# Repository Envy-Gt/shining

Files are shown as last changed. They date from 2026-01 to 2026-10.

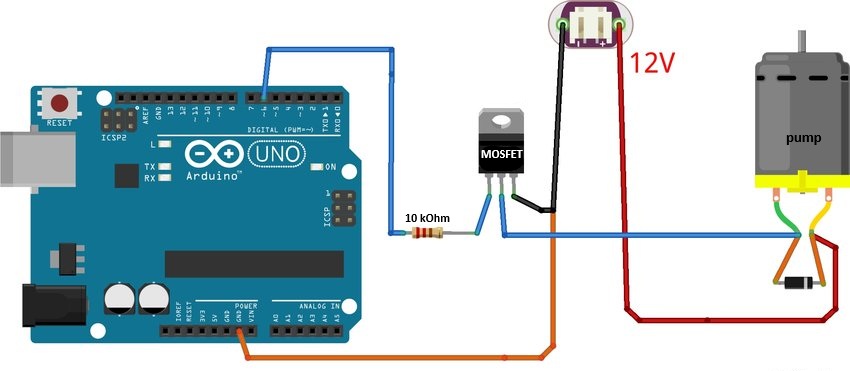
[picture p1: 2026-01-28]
images/wiring/wiring_alim.jpg

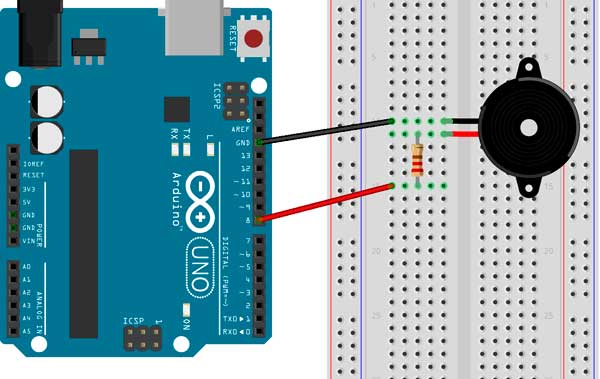
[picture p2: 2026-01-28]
images/wiring/buzzer_wiring.jpg

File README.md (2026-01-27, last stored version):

# shining
Description : Shining is an all in one DIY electroplating machine that answers those constraints : It can be used without an external generator with consistent results even with minimum knowledge of the practice, as safe as possible to use and Fully made with only generic parts and a standard 3D printer

 # What’s electroplating ? 

 Electroplating or electroforming consists of using electricity to depose a thin layer of metal (copper, nickel, palladium, gold…) on a conductive piece.
Electroplating can be used in many diy fields like jewelry, electronics or miniatures painting

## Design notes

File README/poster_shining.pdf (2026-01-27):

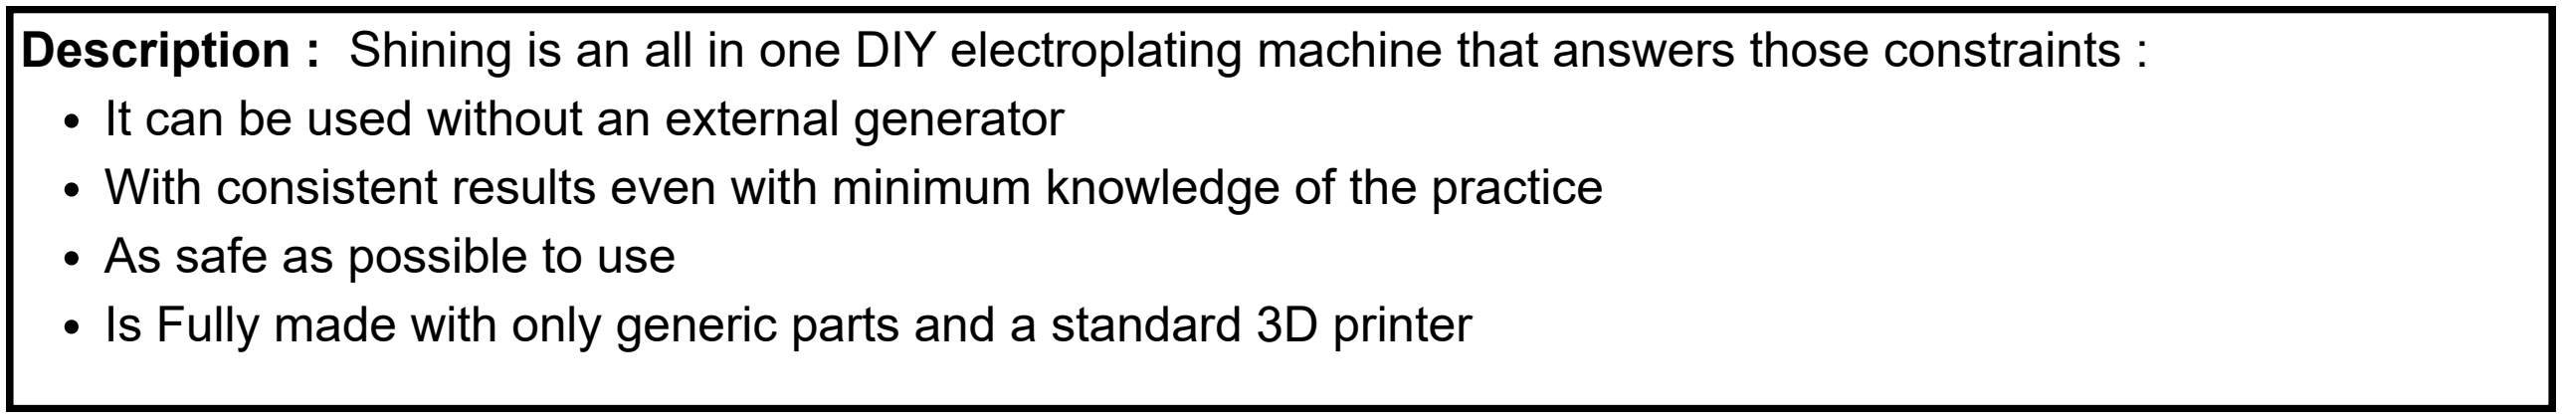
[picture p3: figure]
As safe as possible to use

Description : Shining is an all in one DIY electroplating machine that answers those constraints :

## It can be used without an external generator With consistent results even with minimum knowledge of the practice

## Is Fully made with only generic parts and a standard 3D printer

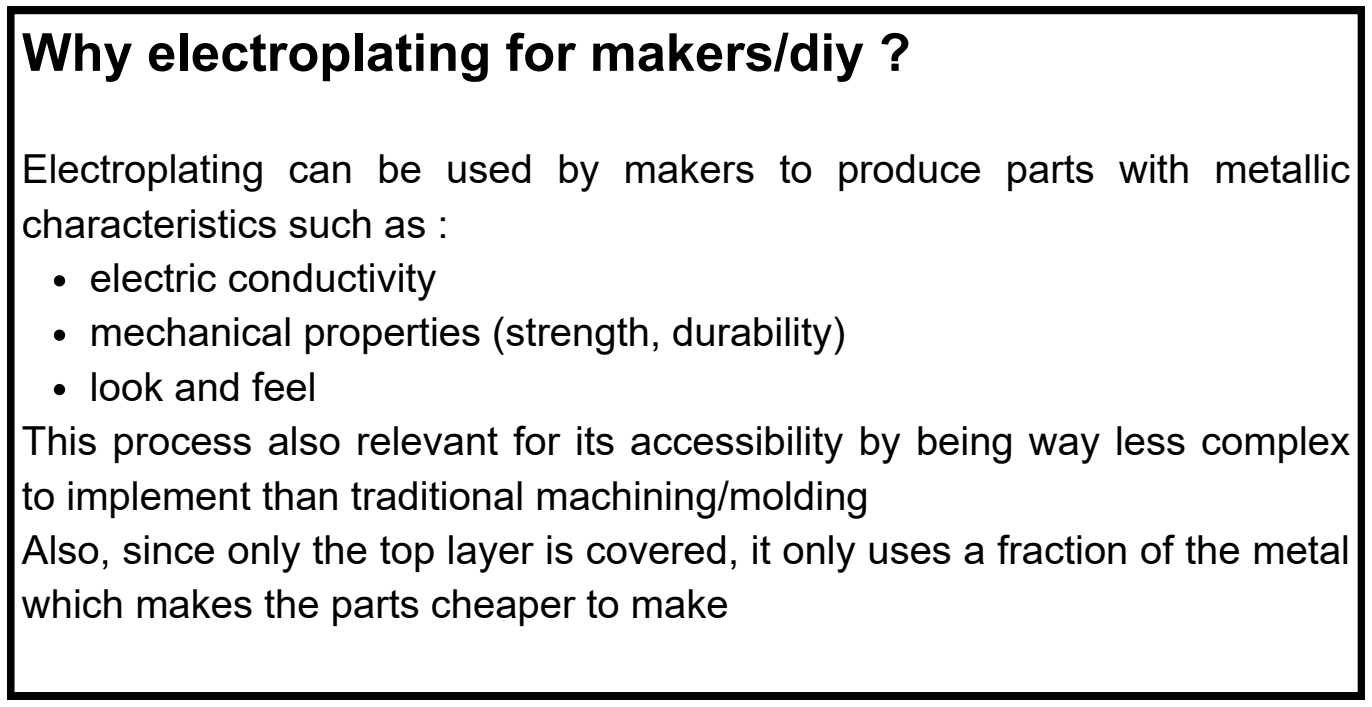
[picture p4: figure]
Why electroplating for makers/diy ?; characteristics such as : electric conductivity mechanical properties (strength, durability) look and feel; to implement than traditional machining/molding; which makes the parts cheaper to make
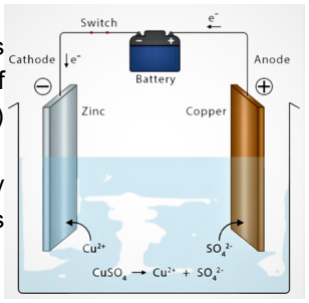
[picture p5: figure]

Electroplating can be used by makers to produce parts with metallic

This process also relevant for its accessibility by being way less complex

Also, since only the top layer is covered, it only uses a fraction of the metal

## What am I proposing ?

This system (shining) aims at being as simple, cheap, and robust as possible.

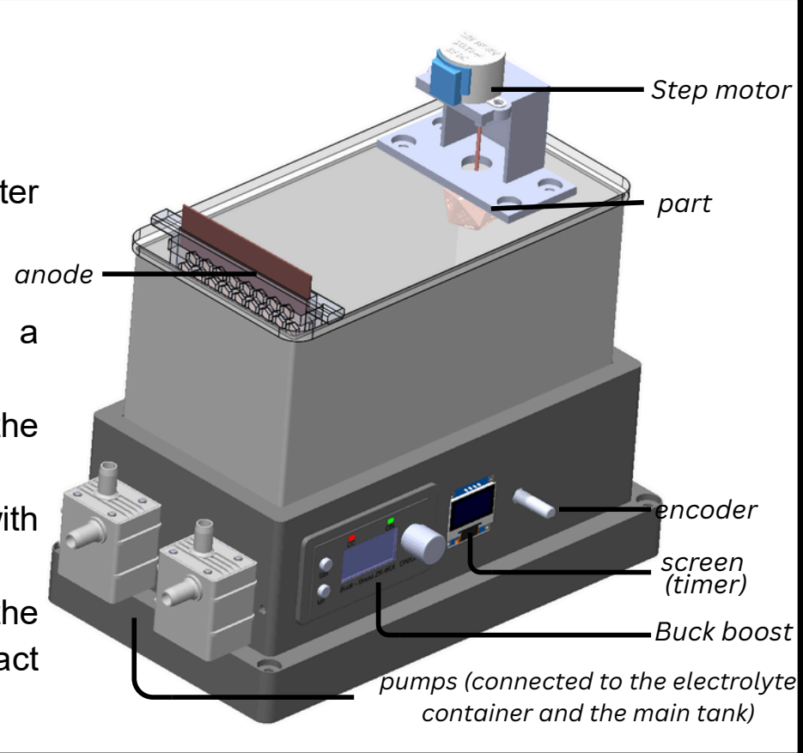
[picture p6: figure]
anode; encoder; screen (timer); Buck boost; part; Step motor; pumps (connected to the electrolyte container and the main tank)

It can be totally assembled for less than 150€ (electrolyte solution aside) with a standard 3D printer and a few generic part (arduino uno, 5V step motor, 12V pumps, encoder, oled screen...)

It works around a Buck Boost Zk-4KX (regularly used to make diy power supplies) which provide a constant current between the part and the anode (copper, nickel, zinc...)
To use it, the user attach the part (connected to the - of the supply) to the step motor and connect the anode (+ of the supply).
They then enter the plating duration with a simple encoder which activated a pump to fill the tank with the acidic electrolyte (closing the circuit and beginning the plating).
The part is rotated in order to assure uniform plating. When the timer ends (the plating stops), the electrolyte solution is sucked out by a second pump and replaced in its container (reducing contact with the user)

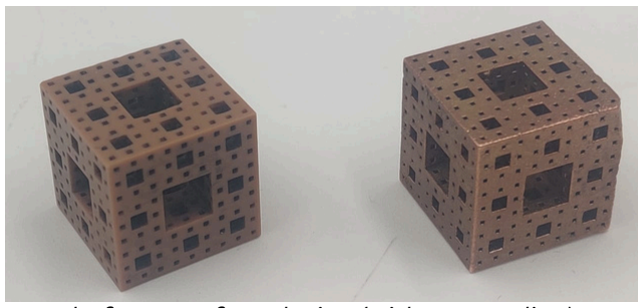
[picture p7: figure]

## My results (so far) :

What works :
+ the parts are evenly plated with a thick coating (+30% in weight)
+ strong bond between the part and the metal (no detachment observed)
+ the plating makes the parts utterly conductive in a way that isn’t attainable with conductive paint

Whats left to improve
- the parts come out rough and need some sanding for a smooth finish
- attaching the part to the step motor and can be a little fiddly
- only works for small parts (> 9 cm in diameter)
- test needs to be done to evaluate the thickness of the coating in order to adjust tolerances for mechanical parts
- a fume extractor is needed to make the system safe in places with not enough ventilation
before plating | after plating and sanding

# SHINING : Conception and Implementation of a Do-It-Yourself

Electroplating Machine Project intended for individual use (makers).

# Augustin Berthomier, Antoine Pradoura, Marc Teyssier

## What’s electroplating ?

Electroplating or electroforming consists of using electricity to depose a thin layer of metal (copper, nickel, palladium, gold…) on a conductive piece.
Electroplating can be used in many diy fields like jewelry, electronics or miniatures painting

before an after plating (without sanding)

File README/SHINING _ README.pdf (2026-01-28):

# SHINING : README

### Components

- 1 Arduino Uno R3 (http://amazon.fr/Arduino-A000066-M%C3%A9moire-flash-32/dp/B008GRTSV6) or any board with the required pins (see the arduino code)
- 1 Buck Boost ZK-4KX (https://www.amazon.fr/Convertisseur-Buck-Boost-dalimentation-Alimentation/dp/B0D44JVLTM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)
- 1 12V 3A power supply (https://www.amazon.fr/LianShi-Alimentation-transformateur-Courts-Circuits-lautomatisation/dp/B073GLDKMH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)
- 1 SSD-1306 (https://www.amazon.fr/dAffichage-Communiquer-R%C3%A9solution-Appareil-Intelligent/dp/B08VJGKCFT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)
- 1 KY-040 encoder (https://www.amazon.fr/AZDelivery-Encodeur-Compatible-Raspberry-incluant/dp/B079H3C98M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)
- 2 12V DC brushless mini pump (https://www.amazon.fr/dp/B0CYC8ZXWH?aref=9a1uacqCT4&sp_csd=d2lkZ2V0TmFtZT1zcF9kZXRhaWwy) or any 12V DC mini pump that doesn’t require to be submerged (a peristaltic pump would be best)
- 1 3-24V buck module step down (https://www.amazon.fr/dp/B0FP51RK8T?aref=6MLL2bEfZb&sp_csd=d2lkZ2V0TmFtZT1zcF9kZXRhaWw)
- 1 28BYJ48 5V stepper + Driver ULN2003A (https://www.amazon.fr/reucteur-28BYJ48-stepper-ULN2003A-Arduino/dp/B071VGBJG3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)
- 2 MOSFET irfz44n (https://www.amazon.fr/Innfeeltech-Transistors-MOSFET-irfz44n-transistor/dp/B0D69Y4GKW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) (would also work with npn mosfets)
- 1 Buzzer 3-24 V (https://www.amazon.fr/sonnerie-%C3%A9lectrique-pi%C3%A9zo-%C3%A9lectrique-%C3%A9lectronique-pi%C3%A9zo%C3%A9lectrique/dp/B08J9TMZSV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)
- 1 galvanization tank (https://drgalva.fr/cuve-pour-galvanisation-grand-fr)
- 1 breadBoard
- Dupont jumper cables (male-male/female-male)
- clear acrylic sheet (3-5 mm)
- 4x6mm clear polyurethane (https://www.amazon.fr/HAXIHA-Pneumatique-Polyur%C3%A9thane-Compresseur-Pneumatiques/dp/B0DQ1HHC8T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) tube
- 3 10k Ohm resistors (https://www.amazon.fr/Sourcingmap-axial-plomb-r%C3%A9sistances-Carbone/dp/B0087ZDQQ0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)
- 4 M4x16mm screws
- 2 M4x8mm screws
- 4 M4 Washers
- 4 M2 screws (for mounting the screen)

### Consumables

- Bright blue copper electrolyte (https://drgalva.fr/cuivre-brillant-fr)
- pure copper anode (https://drgalva.fr/anode-en-cuivre-fr) (or any pure copper sheet)
- Copper threads (1-2mm for holding the part and 0.3-0.8) for best conductivity)
- conductive copper spray (https://www.tifoo.de/fr/spray-conducteur-en-cuivre)

### Equipment

- Standard 3D printer (PLA/TPU)
- Drill with 6mm and 12 mm bits (for the acrylic sheet)
- cutting tools for the acrylic sheet (dremel/handsaw/jigsaw…)
- hot glue gun

### Assembly

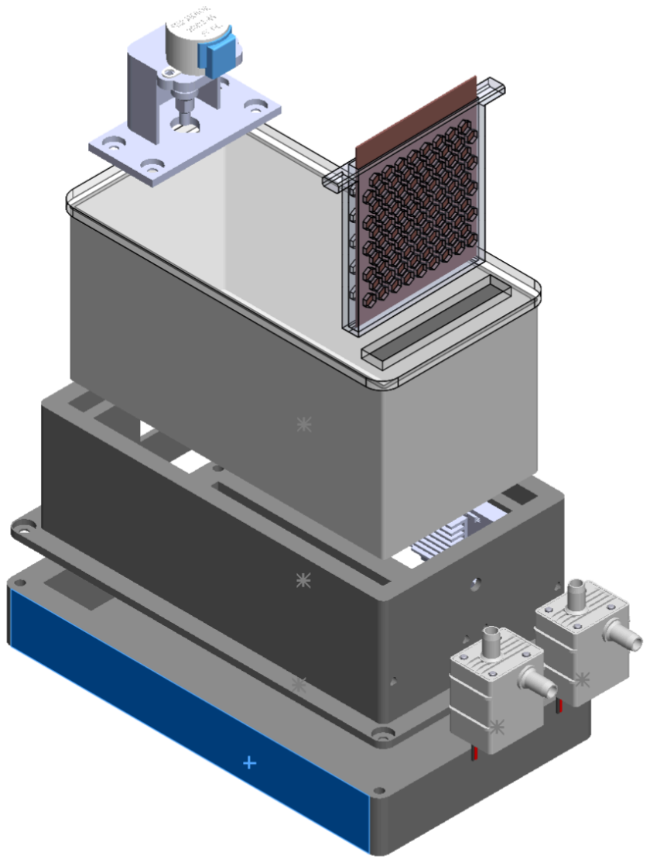
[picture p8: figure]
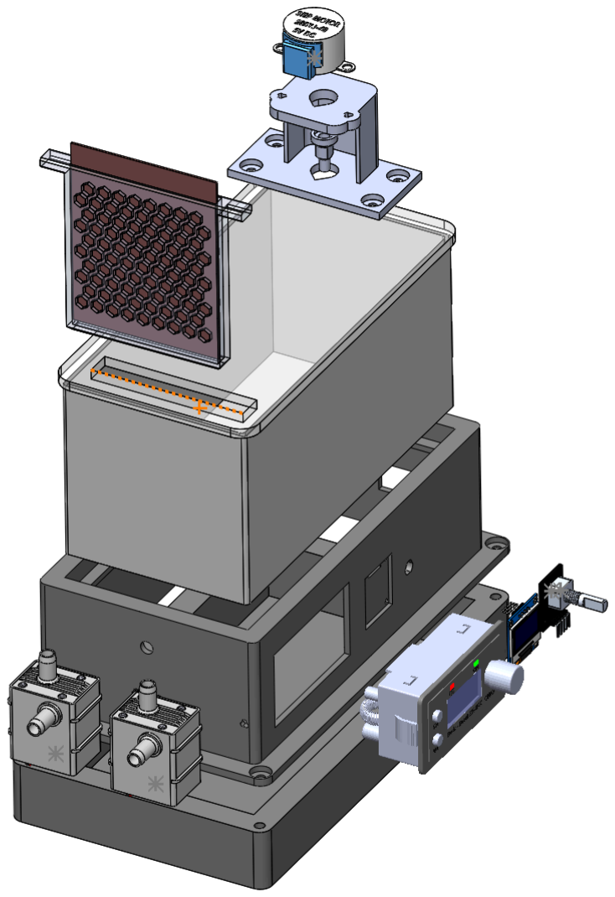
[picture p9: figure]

As seen in those pictures the assembly is pretty straight forward :
- the main frame (box_shining) is screwed on the base with washers and the tank simply sit on top of the mainframe
- the stepper compartment (step_holder) is held by 4 screws going through the acrylic sheet in another 3D printed part (-step_holder_2) (not seen in the 3D view)
- the acrylic sheet can’t be 3D printed, I added a DXF file that can be used as a guide when cutting or if possible, used for laser cutting the sheet
- the joint_TPU_Shining is glued on the acrylic and goes between it and the tank so that the lid does not move during use
- the tube is held in place at the bottom of the place by the embout_shining that is hot glued to the bottom wall (see image_embout)

For the electronic :

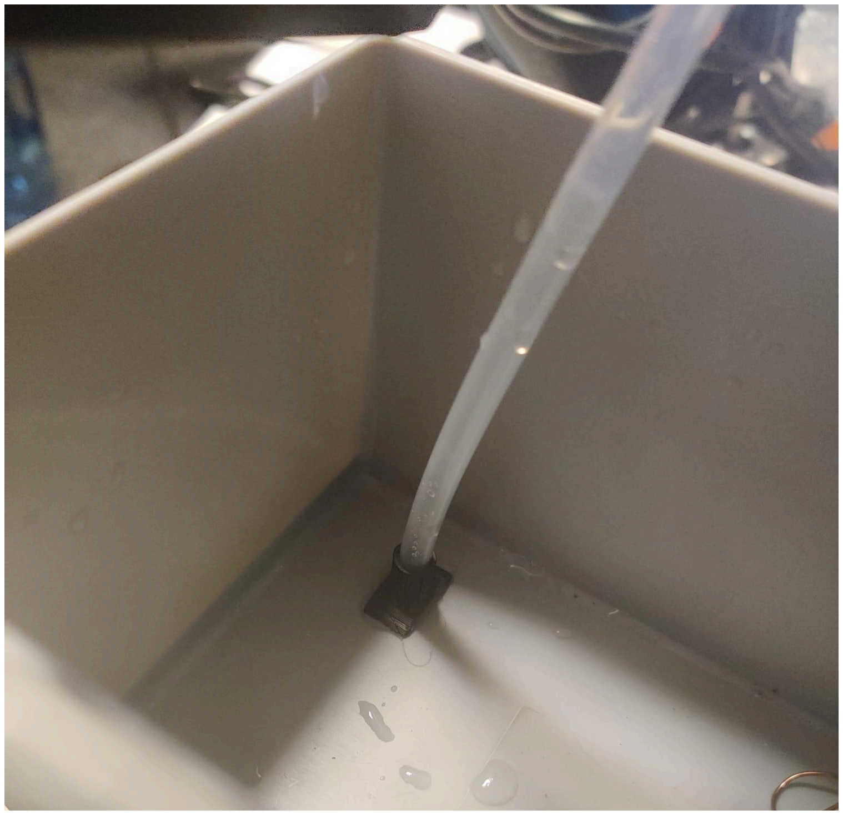
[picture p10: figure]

- the mini pumps are mounted with screws using an attachement, i’m using the one that came with mine but i will model a new one shortly
- the screen in mounted using m2 screws
- the encoder is already tapped and can be screwed directly on the frame
- the buck boost is a simple press fit
- Note that the power supply can’t be properly put in the frame if the buck boost is all the way in. To mount it, get it in by the under side of the frame, press it against the inner wall of the frame and push the buck boost in. it should lock it in place (see image_up).

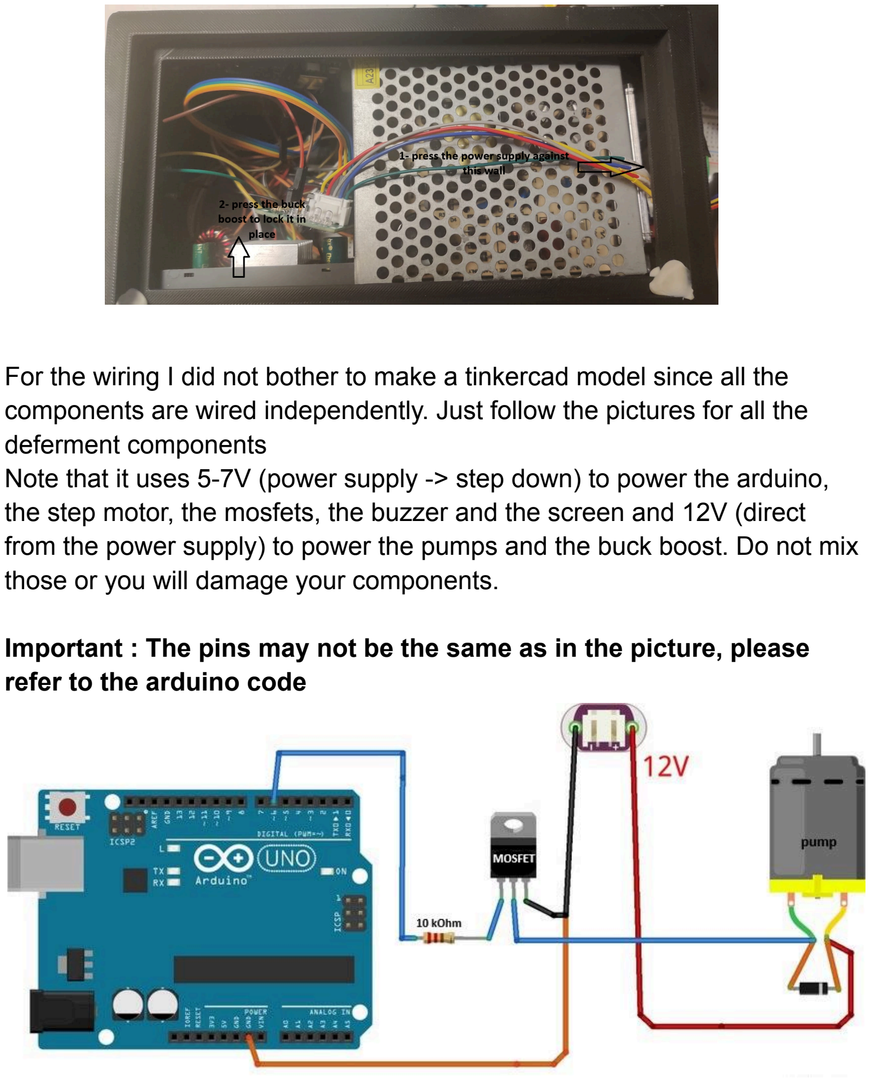
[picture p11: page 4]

For the wiring I did not bother to make a tinkercad model since all the components are wired independently. Just follow the pictures for all the deferment components
Note that it uses 5-7V (power supply -> step down) to power the arduino, the step motor, the mosfets, the buzzer and the screen and 12V (direct from the power supply) to power the pumps and the buck boost. Do not mix those or you will damage your components.

Important : The pins may not be the same as in the picture, please refer to the arduino code

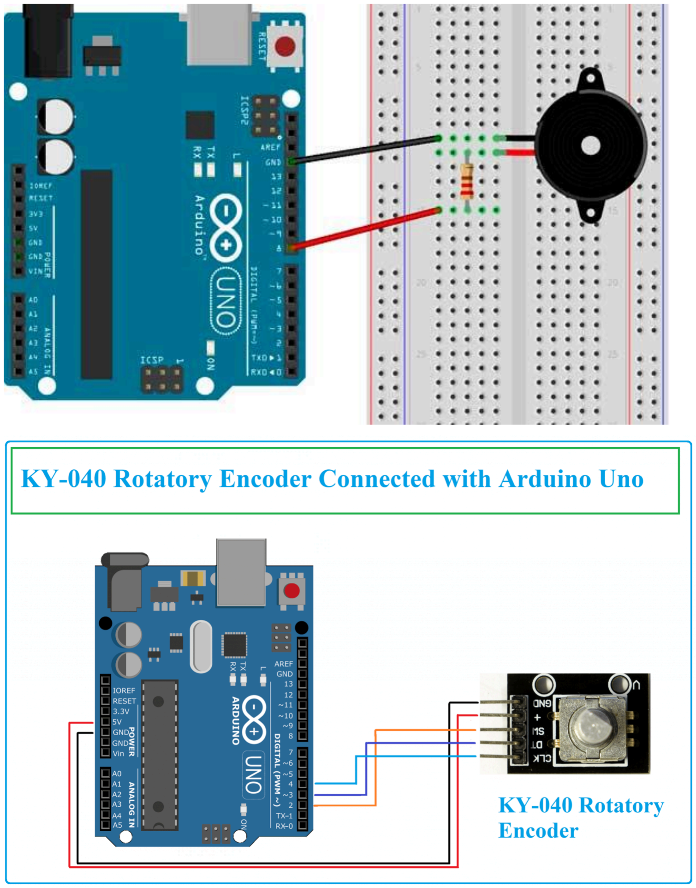
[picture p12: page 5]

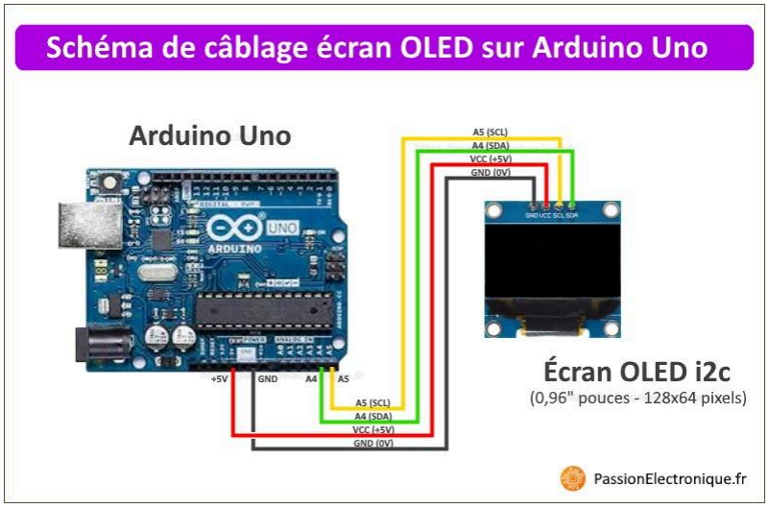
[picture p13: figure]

## How to use

Preparation :
- sand the target part correctly to avoid any imperfection to show through the plating
- spray the target part with a conductive spray (see components)
- once dried, wrap your part with thin copper wire to ensure conductivity
- take the thicker wire to make a hook and attach it to the stepper
- attach the part to the hook inside the tank so that it does not exceed ¾ of its height
- connect the part to the VOUT - and the anode to the VOUT + check the connection with a multimeter
- check that the tubing is well connected between the tank, the pump and the bottle of acid

Use

- 1 : power the device by plugging it (the is not on/off button)
- 2 : use the encoder to choose a timer and click to confirm
- the device will first pump the electrolyte in the tank
- Use the buck boost to choose the current, if everything is well connected and the value is correct (1A per Dm2) the constant current led should light up
- If you want to interrupt the possess, click on the encoder
- Upon interruption or at the end of the timer, the second pump will get the acid back in its bottle
- using gloves, take the piece and rinse it with water to neutralise the last drop of acid.
- you can now sand the piece for better results

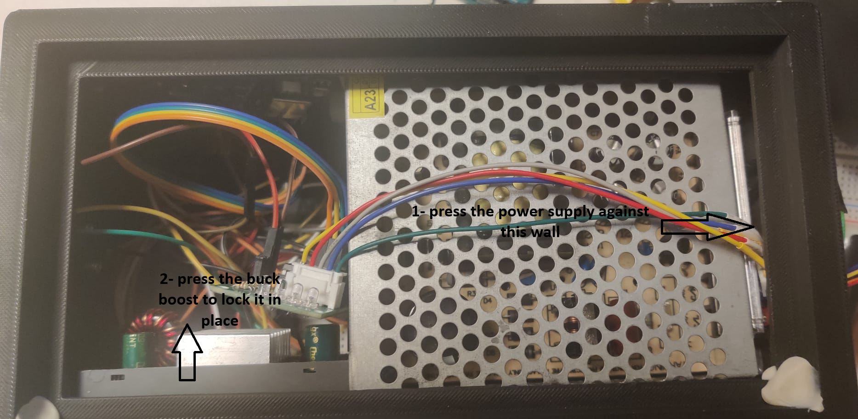
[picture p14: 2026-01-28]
images/pictures/image_up.png

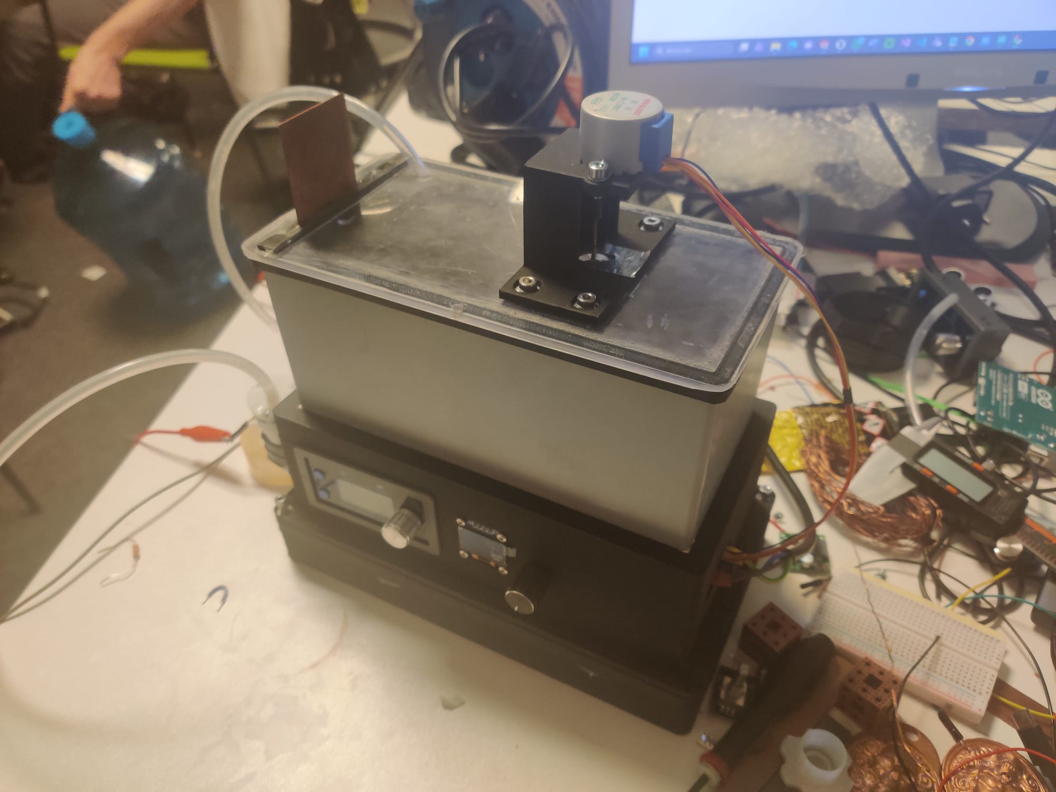
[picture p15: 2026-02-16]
images/pictures/image_whole.jpeg

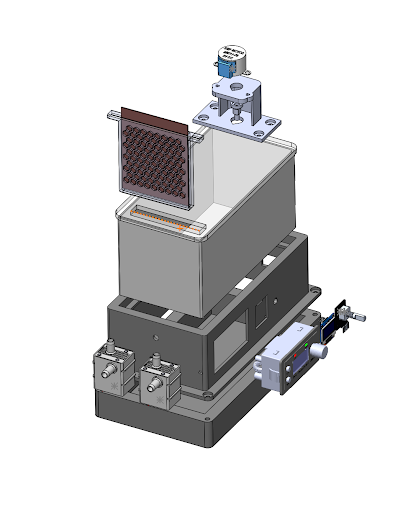
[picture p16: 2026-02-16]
images/3D_View_Shining/3D_View_2.png

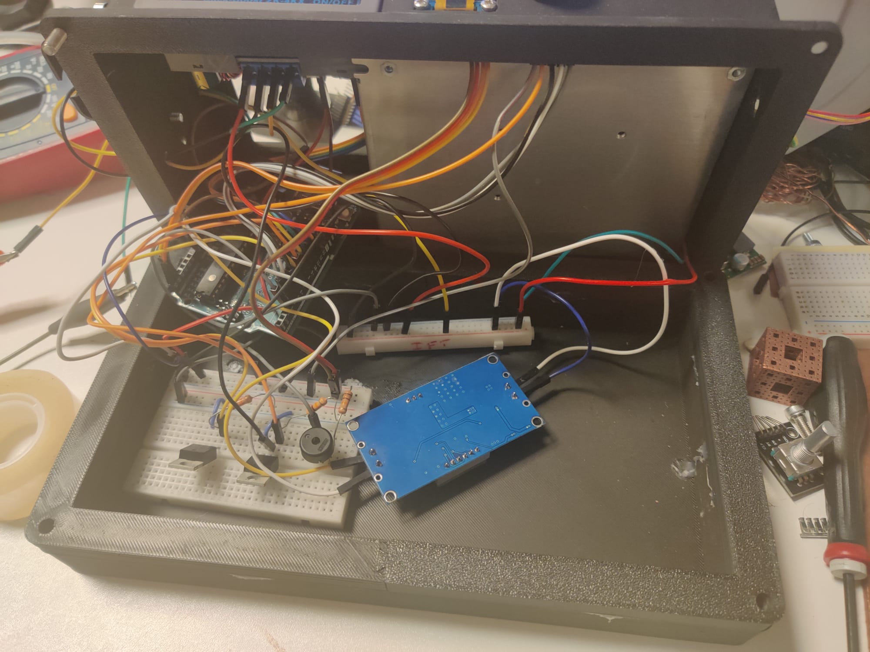
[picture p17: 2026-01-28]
images/pictures/image_inside.jpeg

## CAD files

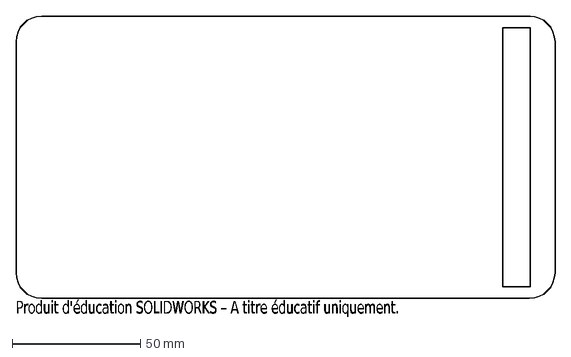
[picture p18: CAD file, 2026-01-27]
stencil for acrilic.DXF
Produit d'éducation SOLIDWORKS – A titre éducatif uniquement.

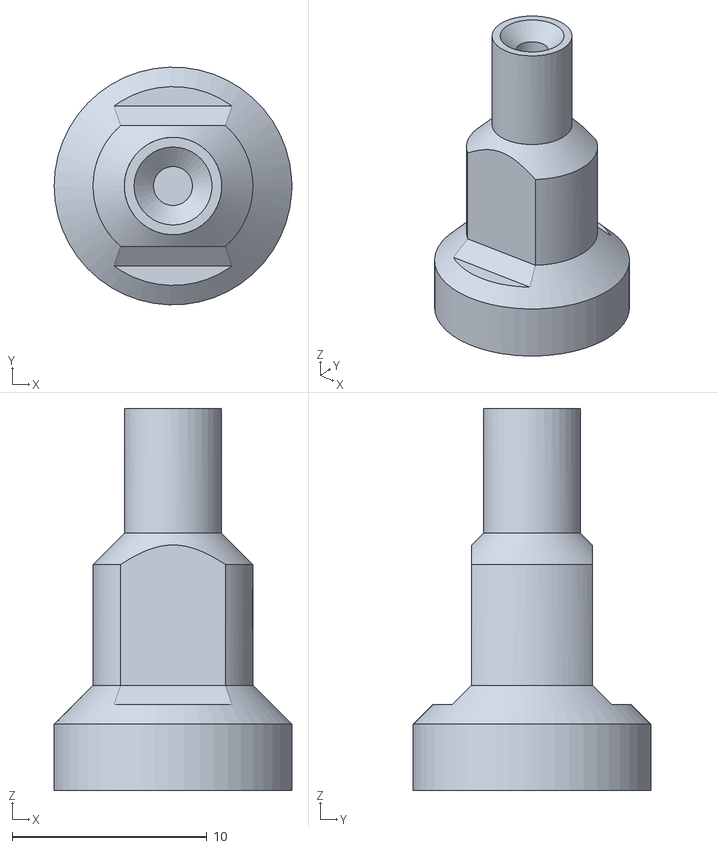
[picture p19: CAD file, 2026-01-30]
STL files/inter_shining.STL
12.2 x 12.2 x 19.6

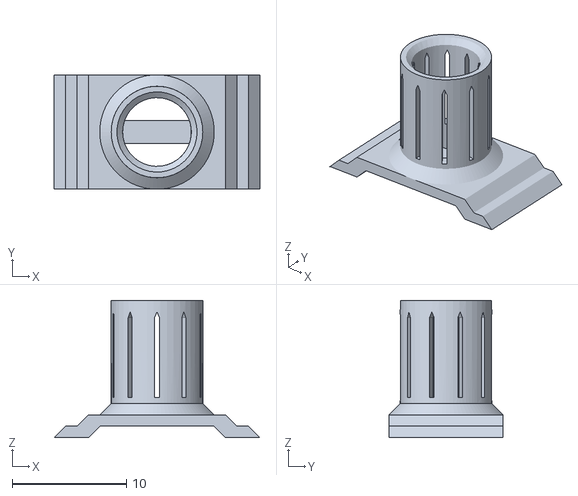
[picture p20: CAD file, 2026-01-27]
STL files/embout_shining.STL
18.0 x 10.0 x 12.0

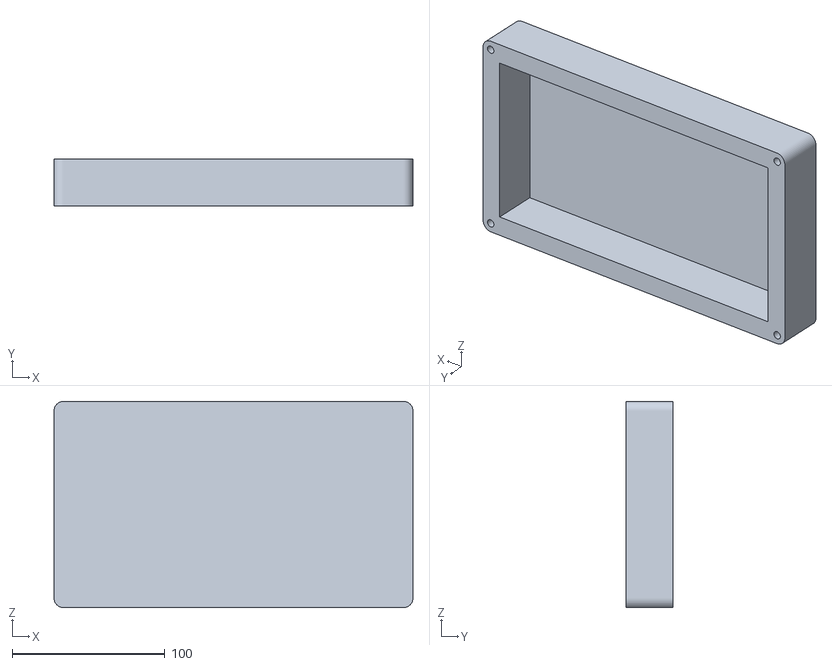
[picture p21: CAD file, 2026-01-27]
STL files/base_shining.STL
235.0 x 31.0 x 135.0

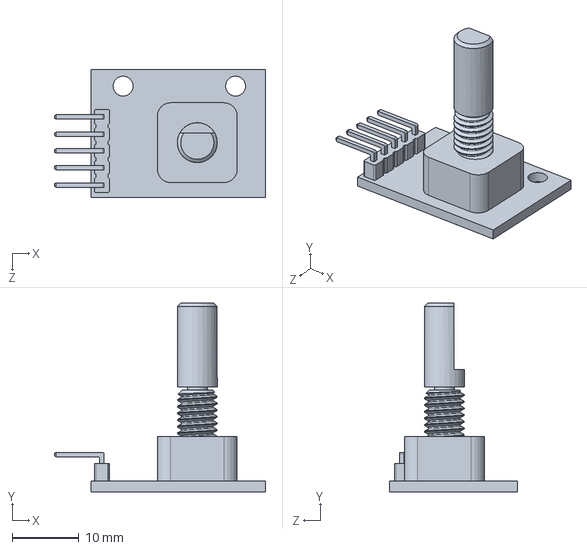
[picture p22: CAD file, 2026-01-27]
SLPRT files/User Library-S002 - Encoder KY040.SLDPRT
31.7 x 28.3 x 19.2 mm

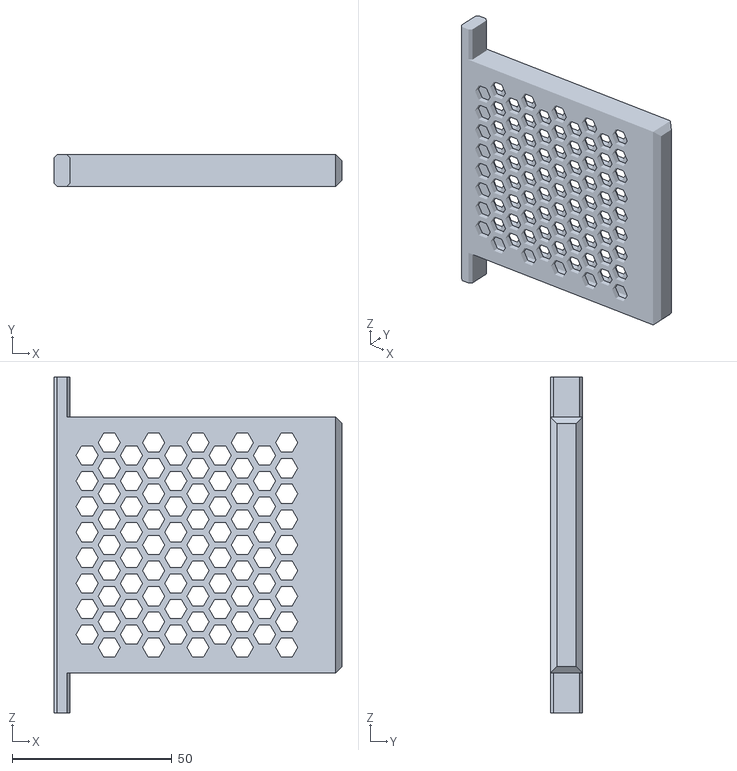
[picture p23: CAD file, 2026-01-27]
STL files/Panier_Shining.STL
90.0 x 10.0 x 105.0

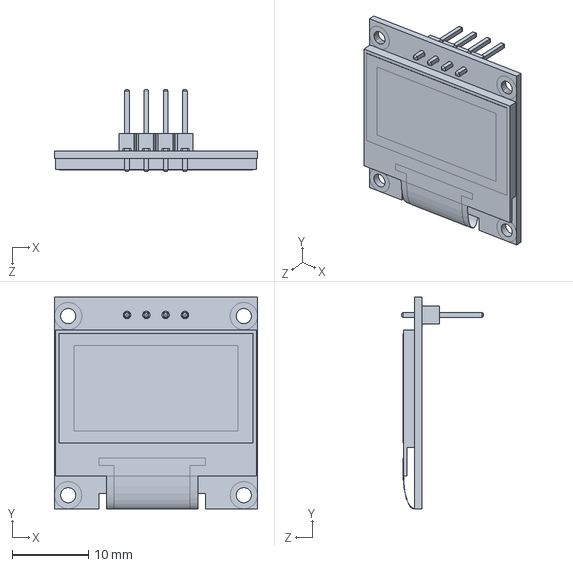
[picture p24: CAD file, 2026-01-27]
SLPRT files/User Library-128x64I2COLEDDisplayAdafruit.SLDPRT
26.7 x 27.9 x 10.8 mm

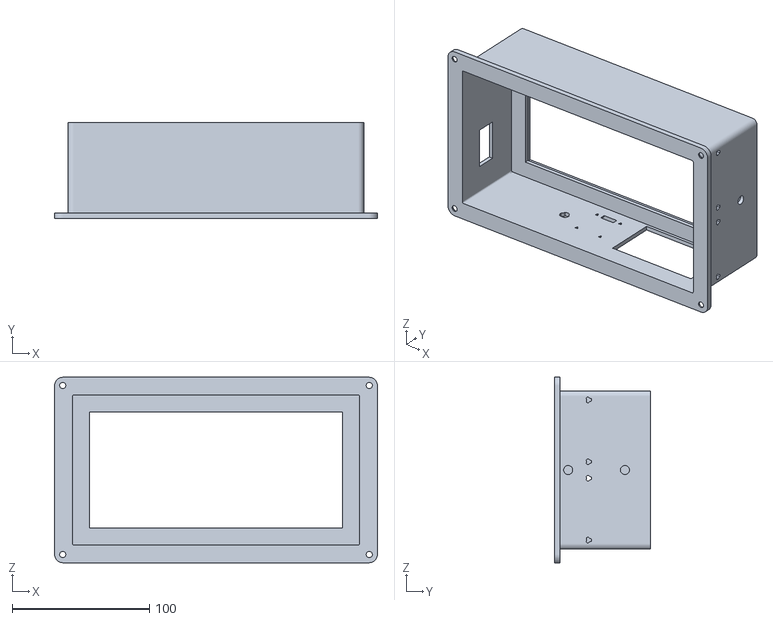
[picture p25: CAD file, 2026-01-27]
STL files/box_shining.STL
235.0 x 70.0 x 135.0

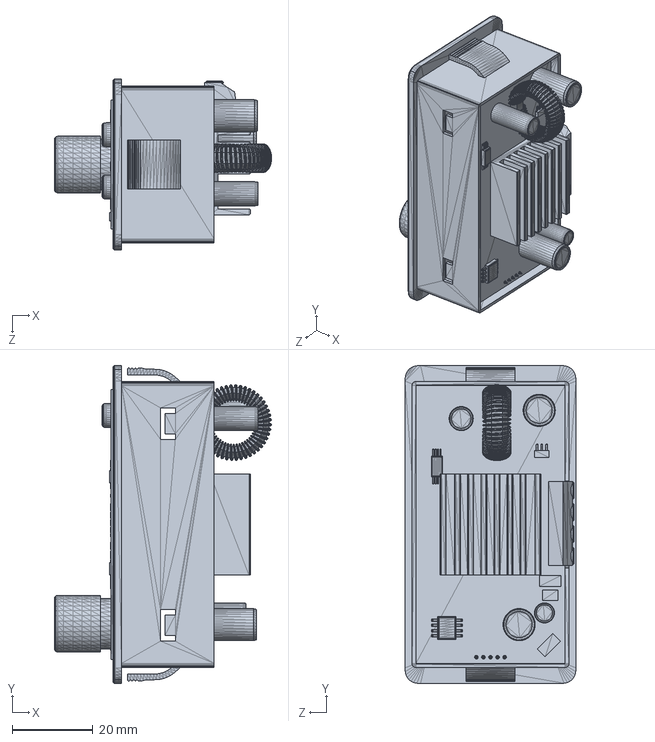
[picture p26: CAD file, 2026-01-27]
SLPRT files/ZK-4KX Buck Boost Converter.SLDPRT
53.9 x 79.0 x 42.5 mm

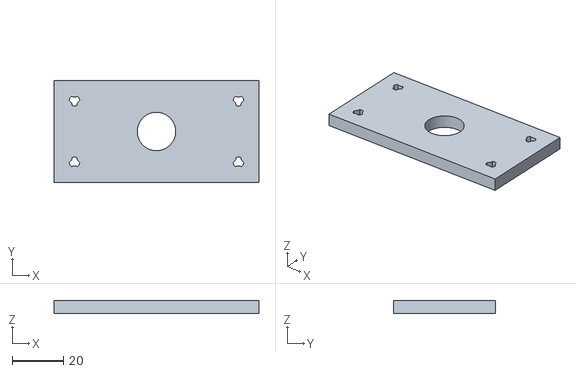
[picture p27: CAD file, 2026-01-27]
STL files/step_holder_2_shining.STL
80.0 x 40.0 x 5.00

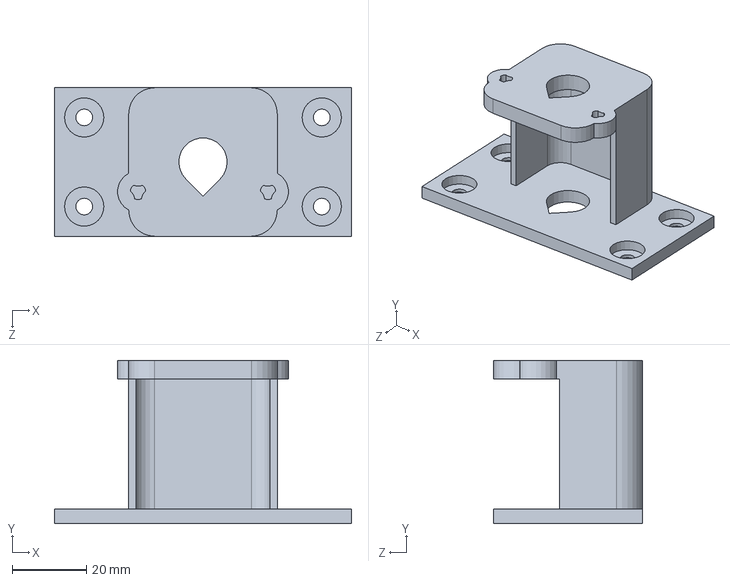
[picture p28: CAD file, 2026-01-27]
SLPRT files/step_holder_shining.SLDPRT
80.0 x 44.0 x 40.0 mm

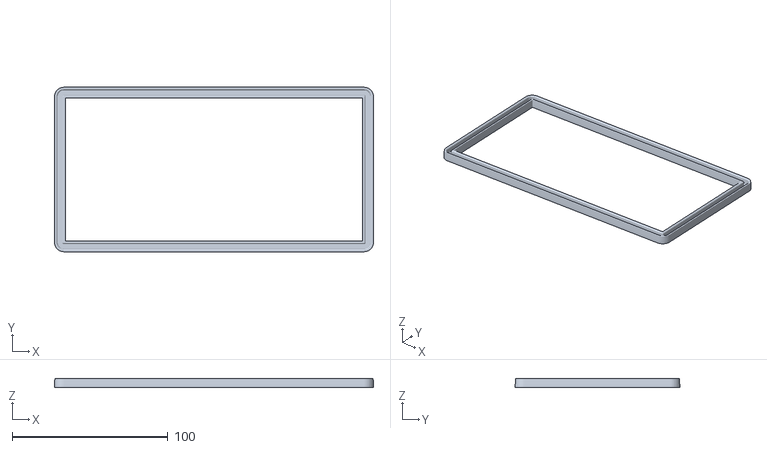
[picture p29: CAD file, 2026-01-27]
STL files/joint_TPU_Shining.STL
204.5 x 105.5 x 6.00

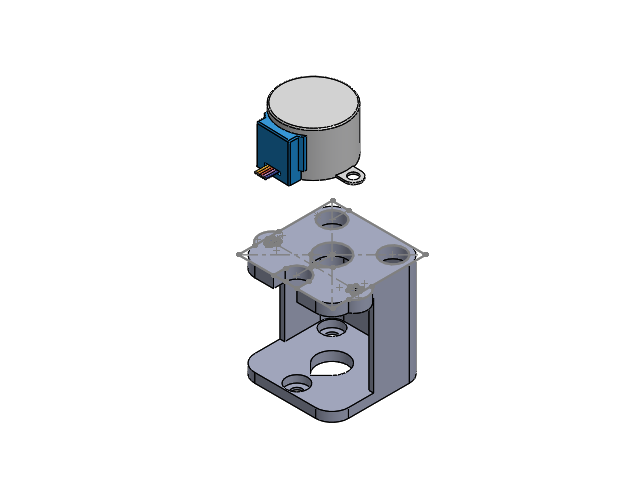
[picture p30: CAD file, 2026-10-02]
SLPRT files/Assemblage step.SLDASM
step holder
28BYJ-48.step

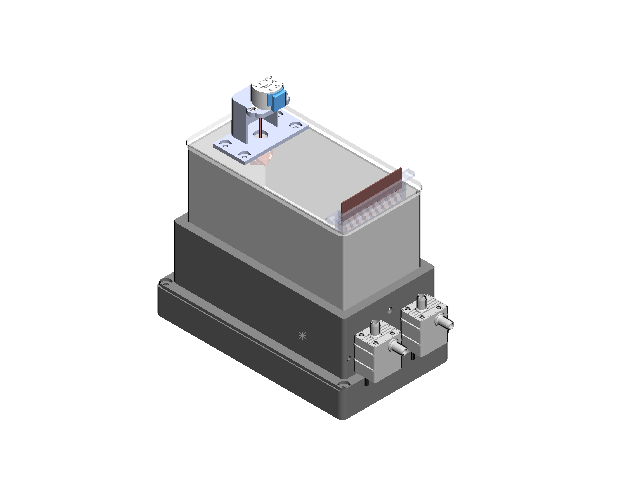
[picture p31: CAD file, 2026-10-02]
SLPRT files/Assemblage shining.SLDASM
box_shining
base_shining
step_holder_shining
Pièce2^Assemblage shining
Pièce3^Assemblage shining
User Library-128x64I2COLEDDisplayAdafruit
User Library-S002 - Encoder KY040
ZK-4KX Buck Boost Converter
Panier_Shining
Pièce10^Assemblage shining
Stepper motor 28BYJ-48 5V
inter_shining
Pièce13^Assemblage shining
Elegance D20 Dots
User Library-QR30E x 2

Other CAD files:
SLPRT files/inter_shining.SLDPRT
STL files/step_holder_shining.STL
SLPRT files/Panier_Shining.SLDPRT
SLPRT files/base_shining.SLDPRT
SLPRT files/Stepper motor 28BYJ-48 5V.SLDPRT
SLPRT files/User Library-QR30E.SLDPRT
SLPRT files/box_shining.SLDPRT

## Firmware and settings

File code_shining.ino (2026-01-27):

#include <Wire.h>
#include <Adafruit_GFX.h>
#include <Adafruit_SSD1306.h>



#include <Encoder.h>

#define POMPE1_PIN 12
#define POMPE2_PIN 7

bool pompe1Active = false;
unsigned long pompe1Start = 0;


// --- OLED ---
#define SCREEN_WIDTH 128

#define SCREEN_HEIGHT 64
#define OLED_ADDR 0x3C
Adafruit_SSD1306 display(SCREEN_WIDTH, SCREEN_HEIGHT, &Wire, -1);

// --- KY-040 Encoder ---
#define ENCODER_CLK 4
#define ENCODER_DT  5
#define ENCODER_SW  6   // Single push button on KY-040
Encoder myEnc(ENCODER_CLK, ENCODER_DT);

// --- Buzzer ---
#define BUZZER_PIN 3


// --- Stepper 28BYJ-48 (ULN2003) ---
#define STEPPER_PIN1 8
#define STEPPER_PIN2 9
#define STEPPER_PIN3 10
#define STEPPER_PIN4 11

int stepIndex = 0;

// Séquence demi-pas
int stepSequence[8][4] = {
  {1, 0, 0, 0},
  {1, 1, 0, 0},
  {0, 1, 0, 0},
  {0, 1, 1, 0},
  {0, 0, 1, 0},
  {0, 0, 1, 1},
  {0, 0, 0, 1},
  {1, 0, 0, 1}
};
unsigned long lastStepTime = 0;
const unsigned long stepInterval = 3; // ms entre pas (réglable)


// --- Timer variables ---
bool timerActif = false;
unsigned long timerDebut = 0;
unsigned long timerDuree = 0;

void setup() {
  Serial.begin(9600);

  pinMode(ENCODER_SW, INPUT_PULLUP);
  pinMode(BUZZER_PIN, OUTPUT);
  pinMode(STEPPER_PIN1, OUTPUT);
  pinMode(STEPPER_PIN2, OUTPUT);
  pinMode(STEPPER_PIN3, OUTPUT);
  pinMode(STEPPER_PIN4, OUTPUT);

  pinMode(POMPE1_PIN, OUTPUT);
  pinMode(POMPE1_PIN, OUTPUT);
  digitalWrite(POMPE1_PIN, LOW);
  digitalWrite(POMPE1_PIN, LOW);


  if (!display.begin(SSD1306_SWITCHCAPVCC, OLED_ADDR)) {
    Serial.println(F("Erreur SSD1306"));
    for (;;);
  }

  display.clearDisplay();
  display.setTextSize(1);
  display.setTextColor(SSD1306_WHITE);
  display.setCursor(10, 25);
  display.println(F("Reglage timer"));
  display.display();

  playEndMusic();
}

void loop() {
  if (!timerActif) {
    int dureeMinutes = setTimer();
    if (dureeMinutes > 0) {
      timerDuree = dureeMinutes * 60000UL;
      timerDebut = millis();
      timerActif = true;

      Serial.print("Timer demarre : ");
      Serial.print(dureeMinutes);
      Serial.println(" min");

      beepBuzzer();
    }
  } else {
    executerTimer();
  }
}

// --- Réglage du timer avec un seul bouton KY-040 ---
int setTimer() {
  int duree = 0;
  bool valide = false;

  long lastEncoderValue = myEnc.read();
  int lastDisplayedDuree = -1;

  unsigned long pressStart = 0;

  while (!valide) {
    // --- ENCODER ROTATION ---
    long encoderValue = myEnc.read();
    long delta = -(encoderValue - lastEncoderValue) / 2;

    if (delta != 0) {
      duree += (delta > 0) ? 10 : -10;
      duree = constrain(duree, 0, 360);
      tone(BUZZER_PIN, 800, 20);
      lastEncoderValue = encoderValue;
    }

    int heures = duree / 60;
    int minutes = duree % 60;

    // --- DISPLAY UPDATE ---
    if (duree != lastDisplayedDuree) {
      lastDisplayedDuree = duree;

      display.clearDisplay();
      display.setTextSize(1);
      display.setCursor(0, 0);
      display.println(F("Reglage du timer :")); 
      display.setCursor(0, 10);
      display.println(F("Tournez encodeur"));
      display.setCursor(0, 20);
      display.println(F("Appui=OK  Long=Annuler"));

      display.setTextSize(2);
      display.setCursor(10, 35);
      if (heures > 0) {
        display.print(heures);
        display.print("h");
        if (minutes < 10) display.print("0");
        display.print(minutes);
        display.print("m");
      } else {
        if (duree < 10) display.print(" ");
        display.print(duree);
        display.print(" min");
      }

      display.drawRect(0, 55, 128, 8, SSD1306_WHITE);
      int progressWidth = map(duree, 0, 360, 0, 126);
      display.fillRect(1, 56, progressWidth, 6, SSD1306_WHITE);

      display.display(); 
    }

    // --- BUTTON PRESS : SHORT = VALIDATE ---
    if (digitalRead(ENCODER_SW) == LOW) {
      delay(30);
      if (digitalRead(ENCODER_SW) == LOW) {

        pressStart = millis();
        while (digitalRead(ENCODER_SW) == LOW) {
          if (millis() - pressStart > 800) {
            // --- LONG PRESS = CANCEL ---
            afficherMessage("Annulation...");
            tone(BUZZER_PIN, 400, 200);
            delay(1000);
            return 0;
          }
        }

        // SHORT PRESS = validate
        beepBuzzer();
        return duree;
      }
    }

    delay(2);
  }

  return duree;
}

// --- Exécution du timer ---
void executerTimer() {
  unsigned long tempsEcoule = millis() - timerDebut;
  unsigned long tempsRestant = (timerDuree > tempsEcoule) ? (timerDuree - tempsEcoule) : 0;

  // --- Pompe 1 : ON pendant 30s au début ---
  if (!pompe1Active) {
    pompe1Active = true;
    pompe1Start = millis();
    digitalWrite(POMPE1_PIN, HIGH);
  }

  if (pompe1Active && millis() - pompe1Start >= 210000UL) {
    digitalWrite(POMPE1_PIN, LOW);
  }

  // --- Cancel with button press ---
  if (digitalRead(ENCODER_SW) == LOW) {
    delay(50);
    if (digitalRead(ENCODER_SW) == LOW) {
      timerActif = false;
      afficherMessage("Timer annule!");
      beepBuzzer();

      // --- Pompe 2 : ON 30s en cas d'annulation ---
      digitalWrite(POMPE2_PIN, HIGH);
      delay(210000);
      digitalWrite(2_PIN, LOW);

      while (digitalRead(ENCODER_SW) == LOW);
      delay(100);
      return;
    }
  }

  // --- Timer finished ---
  if (tempsEcoule >= timerDuree) {
    timerActif = false;
    afficherMessage("Timer termine!");
    playEndMusic();

    // --- Pompe 2 : ON 30s fin du timer ---
    digitalWrite(POMPE2_PIN, HIGH);
    delay(210000);
    digitalWrite(POMPE2_PIN, LOW);

    delay(2000);
    return;
  }

  // --- Stepper movement ---
  runStepper();

  // --- Display each second ---
  static unsigned long lastDisplayUpdate = 0;
  if (millis() - lastDisplayUpdate >= 1000) {
    lastDisplayUpdate = millis();

    int heuresRestantes = tempsRestant / 3600000UL;
    int minutesRestantes = (tempsRestant % 3600000UL) / 60000UL;
    int secondesRestantes = (tempsRestant % 60000UL) / 1000UL;

    display.clearDisplay();
    display.setTextSize(1);
    display.setCursor(0, 0);
    display.println(F("Timer en cours..."));
    display.setCursor(0, 16);
    display.println(F("Appui = Annuler"));

    display.setTextSize(2);
    display.setCursor(10, 35);

    char buffer[16];
    if (heuresRestantes > 0) {
      sprintf(buffer, "%02dh%02dm%02ds", heuresRestantes, minutesRestantes, secondesRestantes);
    } else if (minutesRestantes > 0) {
      sprintf(buffer, "%02dm%02ds", minutesRestantes, secondesRestantes);
    } else {
      sprintf(buffer, "%02ds", secondesRestantes);
    }
    display.print(buffer);

    display.display();
  }
}



// --- Utilities ---
void afficherMessage(const char* message) {
  display.clearDisplay();
  display.setTextSize(1);
  display.setCursor(0, 25);
  display.println(message);
  display.display();
}

void beepBuzzer() {
  tone(BUZZER_PIN, 1000, 500);
  delay(500);
}

void playEndMusic() {
  tone(BUZZER_PIN, 262, 200);
  delay(200);
  tone(BUZZER_PIN, 294, 200);
  delay(200);
  tone(BUZZER_PIN, 330, 200);
  delay(200);
  noTone(BUZZER_PIN);
}

void runStepper() {
  if (millis() - lastStepTime >= stepInterval) {
    lastStepTime = millis();
    stepMotor(true); // sens horaire
  }
}

void stepMotor(bool sensHoraire) {
  if (sensHoraire) {
    stepIndex = (stepIndex + 1) % 8;
  } else {
    stepIndex = (stepIndex + 7) % 8;
  }

  digitalWrite(STEPPER_PIN1, stepSequence[stepIndex][0]);
  digitalWrite(STEPPER_PIN2, stepSequence[stepIndex][1]);
  digitalWrite(STEPPER_PIN3, stepSequence[stepIndex][2]);
  digitalWrite(STEPPER_PIN4, stepSequence[stepIndex][3]);
}

  

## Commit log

2026-01-27 forgot one
    [embout_shining.STL]
2026-10-02 Delete solidworks files/Assemblage shining.SLDASM
    replace by a pack & go
    [Assemblage shining.SLDASM]
2026-10-02 Delete solidworks files/Panier_Shining.SLDPRT
    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
    [Panier_Shining.SLDPRT]
2026-10-02 Delete solidworks files/Stepper motor 28BYJ-48 5V.SLDPRT
    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
    [Stepper motor 28BYJ-48 5V.SLDPRT]
2026-10-02 Delete solidworks files/User Library-128x64I2COLEDDisplayAdafruit.SLDPRT
    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
    [User Library-128x64I2COLEDDisplayAdafruit.SLDPRT]
2026-10-02 Delete solidworks files/User Library-QR30E.SLDPRT
    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
    [User Library-QR30E.SLDPRT]
2026-10-02 Delete solidworks files/ZK-4KX Buck Boost Converter.SLDPRT
    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
    [ZK-4KX Buck Boost Converter.SLDPRT]
2026-10-02 Delete solidworks files/base_shining.SLDPRT
    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
    [base_shining.SLDPRT]
2026-10-02 Delete solidworks files/User Library-S002 - Encoder KY040.SLDPRT
    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
    [User Library-S002 - Encoder KY040.SLDPRT]
2026-10-02 Delete solidworks files/box_shining.SLDPRT
    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
    [box_shining.SLDPRT]
2026-10-02 Delete solidworks files/embout_shining.SLDPRT
    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
    [embout_shining.SLDPRT]
2026-10-02 Delete solidworks files/inter_shining.SLDPRT
    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
    [inter_shining.SLDPRT]
2026-10-02 Delete solidworks files/joint_TPU_Shining.SLDPRT
    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
    [joint_TPU_Shining.SLDPRT]
2026-10-02 Delete solidworks files/step_holder_2_shining.SLDPRT
    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
    [step_holder_2_shining.SLDPRT]
2026-10-02 Delete solidworks files/step_holder_shining.SLDPRT
    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
    [step_holder_shining.SLDPRT]
